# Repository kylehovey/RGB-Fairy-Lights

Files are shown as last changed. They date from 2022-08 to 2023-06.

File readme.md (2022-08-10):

# RGB Fairy Lights

aurora

This project includes all of the firmware and 3D files to create a driver for the RGB fairy lights sold on Adafruit's store. In order to control this light, you will need to be running [Home Assistant](https://www.home-assistant.io/) on a server at your house along with a [MQTT](https://mqtt.org/) broker and Home Assistant [MQTT Integration](https://www.home-assistant.io/integrations/mqtt/).

## Materials

* [Adafruit QT Py ESP32-S3](https://www.adafruit.com/product/5426) (other boards will most likely work)
* [Neopixel Fairy Lights](https://www.adafruit.com/product/4917)
* [5V/2A Power Supply](https://www.adafruit.com/product/276)
* [3 Pin JST SM Plug](https://www.adafruit.com/product/1663)
* [Panel Mount 2.1mm Barrel Jack](https://www.adafruit.com/product/610)
* A diode
* Hookup wire
* Heat Shrink Tubing (highly recommended, but not strictly required)
* USB C Cable
* Some way of mounting your fairy lights where you want them (I used tacks)

## Tools

* Soldering Iron
* Wire Strippers/Cutters
* Solder
* Double-Sided Adhesive (keeps ESP32 in place, I used thick double-sided tape)
* 3D Printer
* Filament

## Printing the Case

I used PLA to print the case. The models are located in the `models` directory of this project, and you can slice them using whatever software you prefer. I used [Cura](https://ultimaker.com/software/ultimaker-cura).

## Assembly

1. Strip the ends of two short wires and solder them to positive and ground on the barrel jack.
2. Add heat shrink for the barrel jack connection.
3. Insert the barrel jack into the case and tighten the nut to fasten it in place.
4. Solder the ground wire to ground on the ESP32
5. Solder the positive wire to the diode, then the diode to 5V on the ESP32 (make sure the polarity is right, and you may want to trim the diode leads to make it a bit shorter)
6. Insert the bare wires from the male end of the JST connector into the upper slot on the case (above the USB slot where the ESP32 sits).
7. Plug in the LED strip to the connector and match up the wires to find out which one is:
  * Ground - Black on the strand
  * Positive Voltage - Red on the strand
  * Data - Green on the strand
8. Solder positive to positive on the ESP32 (shares the same positive connection with the power jack wire you just added).
9. Solder ground to ground on the ESP32 (shares the same ground connection with the power jack wire you just added).
10. Add the double-sided tape to the bottom of the ESP32 and insert the USB C port into the slot in the case, then fold the ESP32 into the walled area in the case (it should be snug).
20. Snap the lid onto the case.
21. If using leaded solder, wash your hands and then wipe down the case with a paper towel and throw the towel away afterwards.

## Flashing

Follow the instructions to get [PlatformIO](https://platformio.org/) set up on your system and open this project using it.

1. Open `main.cpp` in the `src` directory and add your wifi network name and password, as well as the IP address of the MQTT broker.
2. Update the IP address settings to match your subnet/router at home.
3. You may need to comment out the `local_IP` and allow the board to get an IP using DHCP, which you will be able to see over the serial monitor. Once you see the IP address, you can uncomment that line and update the IP to the one it received. Alternatively, just comment out this line entirely and always use DHCP (you won't ever need to know the IP address of your light).

Once this is done, connect the ESP32 driver box to your computer via USB C and compile/upload this code to your board.

## Adding To Home Assistant

Ensure that you have installed [mqtt-cli](https://www.npmjs.com/package/mqtt-cli) and run the script `src/publish_discovery.sh`. This will publish and retain a configuration payload for your device. Ostensibly, this could be sent from the ESP32, but I ran into payload size limitations with the PubSub library I used for MQTT on the ESP32 (and you only need to do this once).

## Controlling Your Strand

Now go into Home Assistant and you should see a new device called "Rainbow Fairy Lights". Add it to a dashboard wherever you would like, and control the color/brightness/patterns using Home Assistant's UI. Enjoy!

## Known Problems

* The settable aurora pattern doesn't work yet... I need to find a good formula to convert RGB to hue.

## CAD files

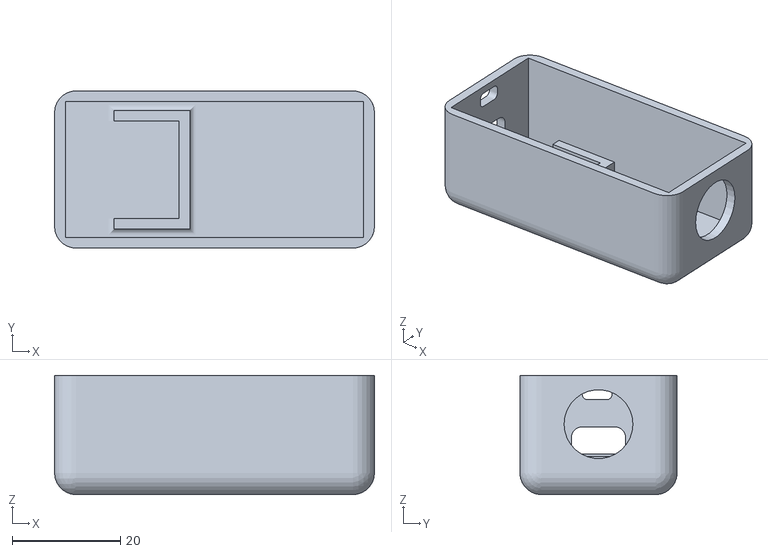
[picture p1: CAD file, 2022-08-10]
models/case.stl
59.0 x 29.0 x 22.0

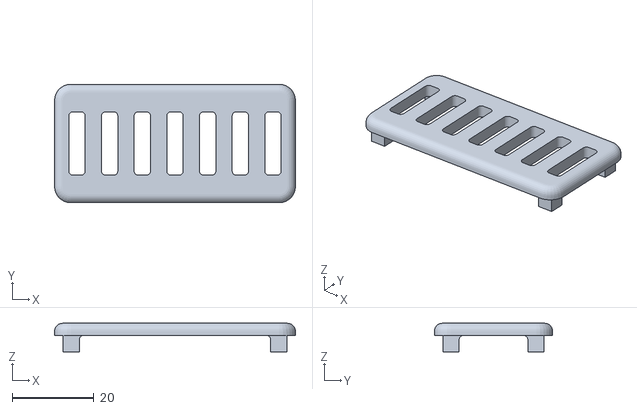
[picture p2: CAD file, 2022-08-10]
models/lid.stl
59.0 x 29.0 x 7.00

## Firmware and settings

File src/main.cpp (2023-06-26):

#include <limits>
#include <Arduino.h>
#include <Adafruit_NeoPixel.h>

#define LED_PIN A0
#define LED_COUNT 100
#define NET_ENABLED

#if (defined(NET_ENABLED))
#include <PubSubClient.h>
#include <WiFi.h>

const char* ssid = "CHANGEME";
const char* password = "CHANGEME";

const char* mqtt_server = "192.168.100.76";

const String mqtt_power_command_topic = "home/light/CHANGEME/power/set";
const String mqtt_rgb_command_topic = "home/light/CHANGEME/rgb/set";
const String mqtt_brightness_command_topic = "home/light/CHANGEME/brightness/set";
const String mqtt_effect_command_topic = "home/light/CHANGEME/effect/set";

const String mqtt_power_status_topic = "home/light/CHANGEME/power/status";
const String mqtt_rgb_status_topic = "home/light/CHANGEME/rgb/status";
const String mqtt_brightness_status_topic = "home/light/CHANGEME/brightness/status";
const String mqtt_effect_status_topic = "home/light/CHANGEME/effect/status";

WiFiClient espClient;
PubSubClient client(espClient);

IPAddress gateway(192, 168, 100, 1);
IPAddress subnet(255, 255, 255, 0);
#endif

Adafruit_NeoPixel strip(LED_COUNT, LED_PIN, NEO_RGB + NEO_KHZ800);

// Adapted from https://stackoverflow.com/a/26233318
int getHue(int red, int green, int blue) {
    float minVal = float(min(min(red, green), blue));
    float maxVal = float(max(max(red, green), blue));
    float hueVal = 0.0;

    if (minVal == maxVal) {
        return 0;
    }

    if (maxVal == red) {
        hueVal = (float(green) - float(blue)) / (maxVal - minVal);
    } else if (maxVal == green) {
        hueVal = 2.0 + (float(blue) - float(red)) / (maxVal - minVal);
    } else {
        hueVal = 4.0 + (float(red) - float(green)) / (maxVal - minVal);
    }

    hueVal = hueVal * 60.0;
    if (hueVal < 0) hueVal = hueVal + 360.0;

    return round(hueVal);
}

int r = 100;
int g = 0;
int b = 100;
int hue = getHue(r, g, b);
int brightness = 255;
String power = "on";
String effect = "fireflies";

#if (defined(NET_ENABLED))
void reconnect() {
  while (!client.connected()) {
    String clientId = "Hannah Fairy Lights";

    if (client.connect(clientId.c_str())) {
      return;
    } else {
      delay(1000);
    }
  }
}

void publishBrightness() {
  int percentage = round(100.0 * float(brightness) / 255.0);

  client.publish(mqtt_brightness_status_topic.c_str(), String(percentage).c_str());
}

void publishRgb() {
  client.publish(mqtt_rgb_status_topic.c_str(), (String(r) + "," + String(g) + "," + String(b)).c_str());
}

void publishPower() {
  client.publish(mqtt_power_status_topic.c_str(), power.c_str());
}

void publishEffect() {
  client.publish(mqtt_effect_status_topic.c_str(), effect.c_str());
}

void onCommand(char* rawTopic, byte* payload, unsigned int length) {
  String topic = String(rawTopic);
  String parsed = String((char*) payload).substring(0, length);

  if (topic == mqtt_power_command_topic) {
    Serial.print("Setting power to ");
    Serial.println(parsed);

    power = parsed;
    publishPower();
  } else if (topic == mqtt_brightness_command_topic) {
    Serial.print("Setting brightness to ");
    Serial.println(String(parsed).toInt());

    brightness = round(255.0 * (String(parsed).toFloat() / 100.0));
    publishBrightness();
  } else if (topic == mqtt_rgb_command_topic) {
    uint8_t firstIndex = parsed.indexOf(',');
    uint8_t lastIndex = parsed.lastIndexOf(',');

    r = parsed.substring(0, firstIndex).toInt();
    g = parsed.substring(firstIndex + 1, lastIndex).toInt();
    b = parsed.substring(lastIndex + 1).toInt();

    publishRgb();
  } else if (topic == mqtt_effect_command_topic) {
    effect = parsed;

    publishEffect();
  }

  Serial.println(topic);
  Serial.println(parsed);
}

void init_mqtt() {
  client.subscribe(mqtt_power_command_topic.c_str());
  client.subscribe(mqtt_brightness_command_topic.c_str());
  client.subscribe(mqtt_rgb_command_topic.c_str());
  client.subscribe(mqtt_effect_command_topic.c_str());

  publishPower();
  publishRgb();
  publishEffect();
  publishBrightness();

  Serial.println("Setting up MQTT callback");
  client.setCallback(onCommand);
}
#endif

// Generated with:
// Array(100).fill().map(() => Math.random()).map(x => x * Math.PI * 2).map(x => x.toFixed(2)).join(',')
float randomPhases[] = {5.04,5.81,4.95,6.19,2.88,3.42,5.60,2.07,5.27,5.89,0.41,3.66,1.61,4.67,6.05,2.91,3.42,0.36,4.71,5.04,4.26,6.15,1.68,1.53,2.43,6.14,4.38,1.80,0.17,5.15,5.11,1.67,5.03,0.31,5.95,1.95,4.91,1.62,3.57,5.43,4.28,2.52,2.22,2.52,5.18,1.20,0.16,0.99,4.23,5.59,1.39,3.46,1.67,5.61,1.12,5.16,1.79,5.49,1.48,0.84,4.61,0.04,2.81,3.15,3.70,2.97,5.27,3.13,1.98,5.28,2.20,0.65,5.42,5.00,1.45,0.91,2.87,4.02,5.46,4.29,5.61,5.87,0.57,0.57,4.80,1.80,6.05,3.96,1.53,0.81,1.73,6.21,2.25,0.95,0.89,3.15,4.28,4.22,4.76,4.43};

float beegHueFromSmol(float hue) {
  return hue * 65535.0 / 360.0;
}

float fireflyActivation(float t, float phase = 0) {
  float E = (sin(t + phase) + cos(5.0*t + phase) - cos(10.0*t + phase) + sin(25.0*t + phase)) / 35.0;
  float x = 20.0 * sin(0.5 * t + phase) / 0.2;
  float fire = 2.0 / (1.0 + exp(x * x));
  float intensity = fire + (1 - fire) * E;

  return intensity;
}

uint32_t fireflyHue(float intensity) {
  float hue = 63.0 * intensity + 262.0 * (1.0 - intensity);
  float beegHue = beegHueFromSmol(hue);

  return uint32_t(beegHue);
}

float fireflyBrightness(float intensity) {
  return float(brightness) / (2.0 * (1.0 + exp(-8.0 * (intensity - 0.5)))) + 0.5;
}

uint32_t auroraHue(float t, float phase, float beginningHue, float endingHue) {
  float intensity = (sin(t + phase) + cos(5.0*t + phase) - cos(10.0*t + phase) + sin(25.0*t + phase)) / 7.05;
  float hue = endingHue * intensity + beginningHue * (1.0 - intensity);
  float beegHue = beegHueFromSmol(hue);

  return uint32_t(beegHue);
}

void init_strip() {
  strip.begin();
  strip.show();
  strip.setBrightness(50);
}

void setup() {
  Serial.begin(112500);

#if (defined(NET_ENABLED))
  Serial.println("Connecting to WiFi");
  WiFi.mode(WIFI_STA);
  WiFi.begin(ssid, password);

  if (WiFi.waitForConnectResult() != WL_CONNECTED) {
    Serial.println("WiFi Failed!");
    return;
  }

  while (WiFi.status() != WL_CONNECTED) {
    Serial.print('.');
    delay(1000);
  }

  Serial.println(WiFi.localIP());

  Serial.println("Connecting to MQTT broker");
  client.setServer(mqtt_server, 1883);

  if (!client.connected()) {
    Serial.println("No connection yet, trying again");
    reconnect();
  }

  Serial.println(client.state());
#endif

  strip.begin();

  init_strip();

#if (defined(NET_ENABLED))
  init_mqtt();
#endif
}

const unsigned long MAXVAL = std::numeric_limits<unsigned long>::max() / 2;

void effectLoop() {
  if (power == "OFF") {
    strip.fill(strip.Color(0, 0, 0));
    strip.show();

    return;
  };


  const auto t = static_cast<float>(millis() % MAXVAL);
  strip.setBrightness(brightness);

  if (effect == "static") {
    strip.fill(strip.Color(r, g, b));
  } else if (effect == "rainbow") {
    const auto iterations = millis() % 128000;
    strip.rainbow(round(256.0 * iterations / 100.0));
  } else if (effect == "fireflies") {
    float pTime = t / 8000.0;

    for (int i = 0; i < LED_COUNT; ++i) {
      float intensity = fireflyActivation(pTime, randomPhases[i]);
      float hue = fireflyHue(intensity);
      float fBrightness = fireflyBrightness(intensity);
      strip.setPixelColor(i, strip.ColorHSV(hue, 255, round(fBrightness)));
    }
  } else if (effect == "aurora") {
    float pTime = t / 4000.0;

    for (int i = 0; i < LED_COUNT; ++i) {
      float hue = auroraHue(pTime, randomPhases[i], 150.0, 220.0);
      strip.setPixelColor(i, strip.ColorHSV(hue, 255, brightness));
    }
  } else if (effect == "auroraSettable") {
    float pTime = t / 4000.0;

    for (int i = 0; i < LED_COUNT; ++i) {
      int deltaHue = 70;
      int startingHue = hue;
      int endingHue = hue + deltaHue % 360;
      float hue = auroraHue(pTime, randomPhases[i], startingHue, endingHue);
      strip.setPixelColor(i, strip.ColorHSV(hue, 255, brightness));
    }
  } else if (effect == "torchlight") {
    float pTime = t / 3000.0;

    for (int i = 0; i < LED_COUNT; ++i) {
      float hue = auroraHue(pTime, randomPhases[i], 18.0, 39.0);
      strip.setPixelColor(i, strip.ColorHSV(hue, 255, brightness));
    }
  }

  strip.show();
}

void loop() {
#if (defined(NET_ENABLED))
  if (!client.connected()) {
    reconnect();
  }

  client.loop();
#endif

  effectLoop();
}

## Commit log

2022-07-31 Using neopixel strip instead of onboard LED
2022-08-09 Updated platform to support ESP32
2022-08-09 Fixed command/state parsing so that power/brightness works on pattern mode
    [main.cpp]
2022-08-09 Fixed the color schemes for all patterns
    [main.cpp]
2022-08-09 Fixed brightness publication and attempted to add new settable pattern
    [main.cpp]
2022-08-10 Added instructions and case files
    [case.stl, lid.stl]
2022-08-10 Added note about diode
2023-06-26 Fixed wifi bug, allowed wifi/MQTT code to be excluded from build, fixed rollover bug
    [main.cpp]
2023-06-26 Hopefully fixed overflow error
    [main.cpp]
